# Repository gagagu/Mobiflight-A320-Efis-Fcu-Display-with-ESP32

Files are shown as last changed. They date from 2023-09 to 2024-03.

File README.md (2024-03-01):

# Mobiflight-A320-Efis-Fcu-Display-with-ESP32
A320 Efis/Fcu Display for Mobiflight with Esp32

## please read!
Eral has taken my project and created a new project as custom device for Mobiflight, so there is no need for using an ESP32 anymore.
See [here](https://github.com/elral/MF_FCU_EFIS_OLEDs)

## This project ist still in development!

The goal of this project is to create an A320 Efis and Fcu controlled by Mobiflight. I want to use it with Fexis A320 for MSFS 2020 but for make it easier on development i have used the A320 from FlyByWire first.

## old The Idea
Mobiflight (today) is not able to control Oled Displays so it's not possible to create Displays like neede for FCU or EFIS with different graphic content. But Mobiflight is able to use Text LCD Display. May idea was/is to use an Arduino to emulate an LCD Display but instead of sending text from Mobiflight to the display i will send commands. The Arduino receives the commands and sets the content of the Oled Display corresponding to the command.

For Example:
In Flightsim we pull the baro knob. Mobiflight detect this and send an command "setSTD" to the LCD Display by I2c bus. The Arduino receives the command and print "STD" to the Oled Display.

### In the project directories are always two subdirectories, "EfisOnly" and "EfisAndFcu". The first one is used the "old" idea. The second one is used the "new" idea (see below).

## the new Idea
With the new (in beta yet) Mobiflight feature for generic I2C Devices the emulation of the LCD Display is not needed anyore. There is now a direct i2c communication between the ESP32 and the Arduino Mega 2560 (Mobliblight).
This makes the code and Mobiflight handling easier.

## The Reality
In reality a Ardunio cannot be i2c bus master and slave, so it wasn't possible to communicate with Mobiflight and the Oled Display on one bus. I have made some tests to use the hardware i2c bus for Mobiflight communication and a Software emulated i2c bus for the Oled Display. It work.... (see: https://github.com/gagagu/Mobiflight-A320-Efis-Display-with-Arduino)
But not really good. It's too slow.

Thats the reason why I switched to an ESP32 board, which has two hardware i2c interfaces.
I've made my first tests only with one Oled Display for the left Efis and everything works fine.

Now, I am working on an extension to realize left and right Efis and the Fcu with one Esp32, for the Displays. Because the displays used all the same i2c address i have to add an i2c multiplexer to controll all displays.
You will need nearly three Arduino Mega 2560 for all Efis and Fcu Buttons and LED's to control. Yes, you can use Portexpander to use one Arduino Mega, but why. The expander is not much cheaper than an additionally used Arduino Mega....

## Current State
The code is nearly finished and the displays are working. For easier testing i have used the Fly By Wire A320 with Mobiflight and i am using the Mobiflight 10

## Installation
- Upload the EfisAndFcu.ino to yout ESP32 with Arduino Studio
- download the latest Mobiflight from GitHub (https://github.com/MobiFlight/MobiFlight-Connector/releases)
- download the lastest mobiflight_genericI2C_mega_<version>.hex from Mobiflight Firmware Source (https://github.com/MobiFlight/MobiFlight-FirmwareSource/releases) and copy it to the Mobniflight/Firmware directory
- download the mobiflight.gagagu_efis_fcu.device.json from my Repository (https://github.com/gagagu/Mobiflight-A320-Efis-Fcu-Display-with-ESP32/tree/main/Mobiflight/EfisAndFcu/Devices) and copy it to the Mobiflight/Devices directory.
- copy the mobiflight_genericI2C_mega.board.json from Mobiflight/Community/MobiFlight/boards to the Mobiflight/Boards directory.
- Start Mobiflight
- Upload the Mobiflight GenerisI2C Mega Firmware für the FCU Arduino
- Upload the FCU.mfmc (https://github.com/gagagu/Mobiflight-A320-Efis-Fcu-Display-with-ESP32/tree/main/Mobiflight/EfisAndFcu) Config to the FCU Arduino
- I am using a second Arduino Mega for the EFIS Knops and buttons (not display) and upload the "normal" Mobiflight firmware to ut and upload the EFIS_LEFT.mfmc to it.
- Open the  FBW_A320_EfisAndFcu.mcc (https://github.com/gagagu/Mobiflight-A320-Efis-Fcu-Display-with-ESP32/tree/main/Mobiflight/EfisAndFcu) in Mobiflight and push "run" (MSFS 2020 with FlyByWire A320 shoudl be running).

## Where are the stl's
I will create a folder with all stl files, soon. Or i will release them on Thingiverse and post the link here.

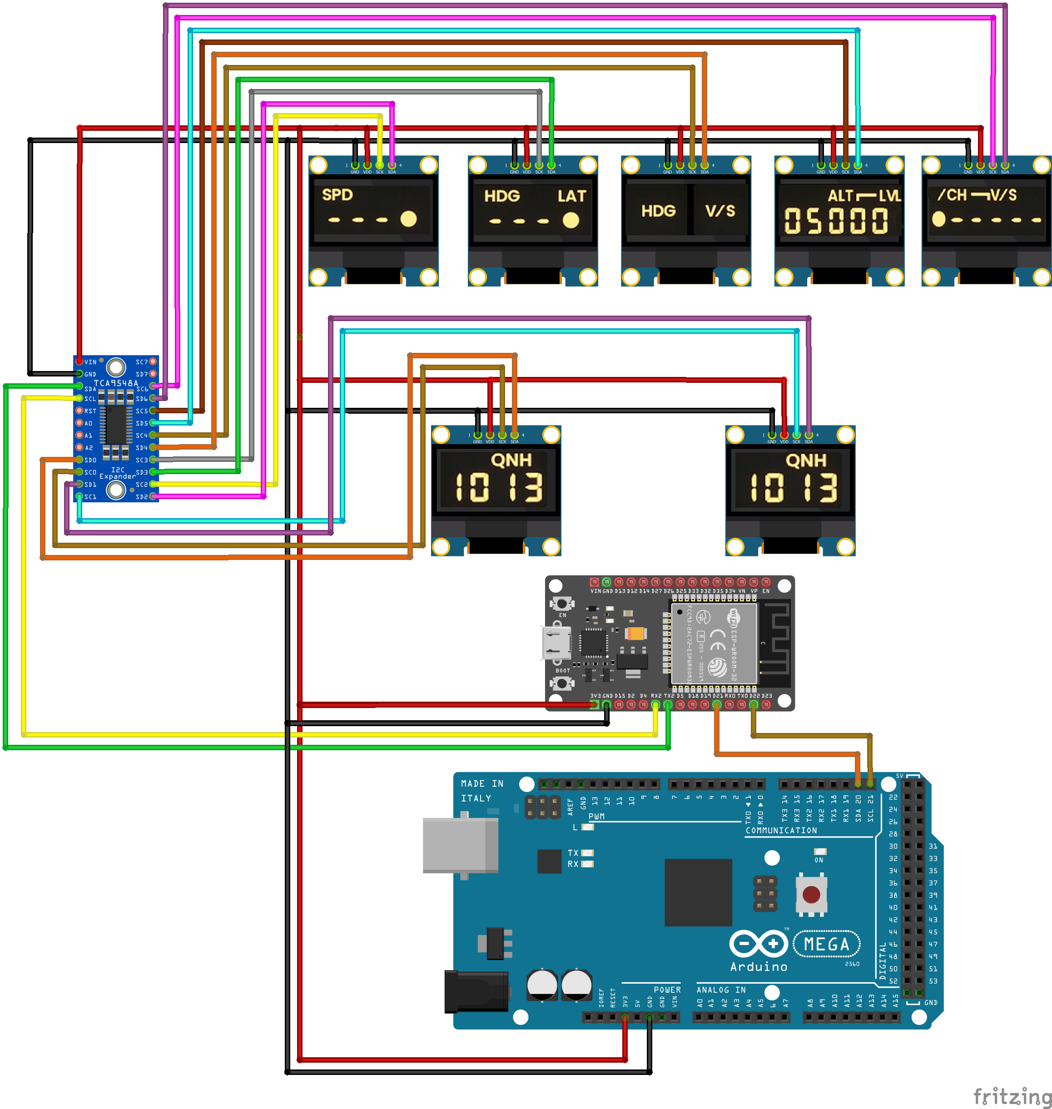
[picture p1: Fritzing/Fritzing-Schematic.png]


## Used designs
https://www.printables.com/de/model/494654-airbus-a320-efis-baro-knob

https://cults3d.com/en/3d-model/game/rotary-switch-5-x-45

https://www.thingiverse.com/thing:5253832

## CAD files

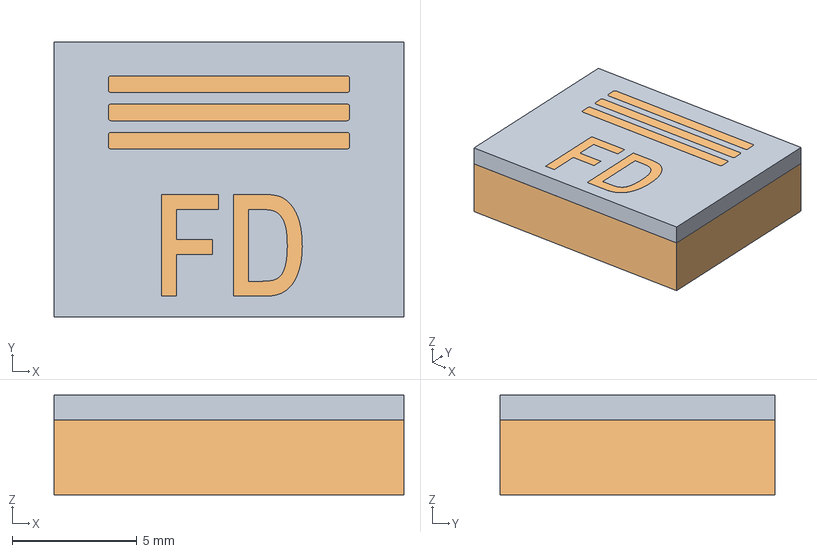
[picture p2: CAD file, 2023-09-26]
FreeCad/Korry/MulticolorPrinter/Korry_Multicolor.FCStd
14.0 x 11.0 x 4.00 mm
Schrift
Kappe

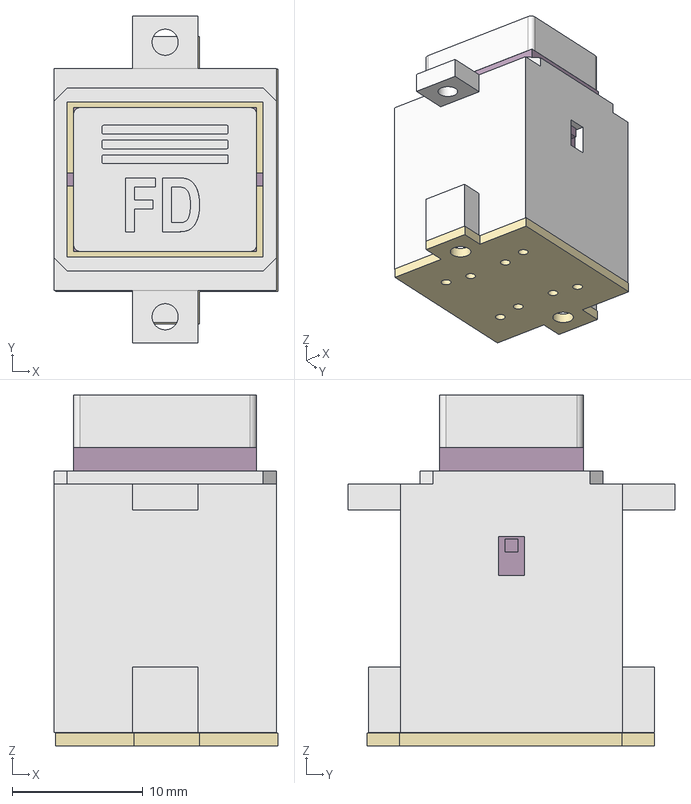
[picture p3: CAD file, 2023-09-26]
FreeCad/Korry/NonMulticolorPrinter/KorryNonMulticolor.FCStd
17.1 x 25.0 x 26.9 mm
inner
Platte

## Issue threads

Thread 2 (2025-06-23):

Frimware dont work

Albatrosnw19, 2025-06-23:
I have connected mega2560 and ESP32 but they are dont work.
1. I cant upload 'mobiflight_genericI2C_mega_2_5_1" to the 2560. it give me foult "There was an error on uploading the frimware to the board"
              23.06.2025 10:35:16(161): ExternAskToCheckLastVersion START from args -> Check BETA False
              23.06.2025 10:35:16(162): GetTheLastVersionNumberAvailable -> 10.5.3.0
              23.06.2025 10:35:16(163): GetInstalledVersion : detected -> 10.5.3.7
Also error if I try 10.5.3.0 version of mobiflight.
After I install version 2_5_0 of frimware I have next problems:
2. Only two displays are working after start boards (EFIS R and L). Another 5 (FCU) only after hot reconnect with TCA9548A.
3. On mobiflight I can see change digits (QNH) 1013,12,14... It is working, but on display only 1013!

gagagu, 2025-06-23:
Hi, have you ssen this?

_Eral has taken my project and created a new project as custom device for Mobiflight, so there is no need for using an ESP32 anymore. See [here](https://github.com/elral/MF_FCU_EFIS_OLEDs)_

Albatrosnw19, 2025-06-23:
There are too little description. Ok, thanks! I will write to him.

gagagu, 2025-06-24:
The Mobiflight Discord Server is a good way to contact him or me if you have further questions.

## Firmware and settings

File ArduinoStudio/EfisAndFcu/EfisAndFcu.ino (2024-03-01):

/*
This is only a Test and has to be set in an usable state
*/

//***************************************************************************************************
// comment this line if you are using (normally 1,3 inch) SH1106G displays for EFIS like following:
// #define EFIS_SSD1306_DISPLAYS 1
// 
// leave this line as it is if you are using (normally 0,9 inch) SSD1306 Displays for EFIS
#define EFIS_SSD1306_DISPLAYS 1
//***************************************************************************************************

#include <Wire.h>
#include <Adafruit_GFX.h>
#include <Adafruit_SSD1306.h>
#include <Adafruit_SH110X.h>
#include <Fonts/FreeSans18pt7b.h>
#include <Fonts/FreeSans9pt7b.h>
#include "Fonts/FreeSans8pt7b.h"
#include "Fonts/FreeSans7pt7b.h"
#include "Fonts/FreeSans6pt7b.h"
#include "Fonts/DSEG7Classic_Regular14pt7b.h"
#include "Fonts/DSEG7Classic_Regular15pt7b.h"
#include "Fonts/DSEG7Classic_Regular16pt7b.h"
#include "Fonts/DSEG7Classic_Regular18pt7b.h"
#include "Fonts/DSEG7Classic_Regular20pt7b.h"  //https://github.com/keshikan/DSEG and https://rop.nl/truetype2gfx/
#include "Fonts/DSEG7Classic_Regular22pt7b.h"

// Address and communication for Mobiflight
#define I2C_MOBIFLIGHT_ADDR 0x27
#define I2C_MOBIFLIGHT_SDA 21
#define I2C_MOBIFLIGHT_SCL 22

// I2c ports for communication with displays
#define I2C_DISPLAY_SDA 17
#define I2C_DISPLAY_SCL 16

#define SCREEN_WIDTH 128    // OLED display width, in pixels
#define SCREEN_HEIGHT 64    // OLED display height, in pixels
#define OLED_RESET     -1   // Reset pin # (or -1 if sharing Arduino reset pin)
#define SCREEN_ADDRESS 0x3c // address of the displays. All displays uses the same address

// address of the multiplexer to change the channels
#define TCA9548A_I2C_ADDRESS  0x70
#define TCA9548A_CHANNEL_EFIS_LEFT  0
#define TCA9548A_CHANNEL_EFIS_RIGHT 1
#define TCA9548A_CHANNEL_FCU_SPD    2
#define TCA9548A_CHANNEL_FCU_HDG    3
#define TCA9548A_CHANNEL_FCU_FPA    4
#define TCA9548A_CHANNEL_FCU_ALT    5
#define TCA9548A_CHANNEL_FCU_VS     6
#define TCA9548A_CHANNEL_UNUSED     7

#define MAX_LENGTH_MESSAGE          96 

enum {
    NOT_SYNCHRONIZED = 0,
    RECEIVE_COMMAND,
    RECEIVE_DATA
};
#define END_OF_I2C_MESSAGE              0x00
#define END_OF_I2C_COMMAND              0x0D      // carriage return in ASCII
#define END_OF_I2C_PARTIAL_MESSAGE      0x0A      // line feed in ASCII
int16_t _messageID = 0;
char _message[MAX_LENGTH_MESSAGE];
//bool _message_received = false;

TwoWire I2Ctwo = TwoWire(1);  // init second i2c bus

// Efis displays
#ifdef EFIS_SSD1306_DISPLAYS
  Adafruit_SSD1306 dEfis(SCREEN_WIDTH, SCREEN_HEIGHT, &I2Ctwo, OLED_RESET);
#else
  Adafruit_SH1106G dEfis = Adafruit_SH1106G(SCREEN_WIDTH, SCREEN_HEIGHT, &I2Ctwo, OLED_RESET);
#endif

// fcu displays
Adafruit_SH1106G dFcu = Adafruit_SH1106G(SCREEN_WIDTH, SCREEN_HEIGHT, &I2Ctwo, OLED_RESET);


// Efis left
char efisLeftBaroMode = 0x00;
char efisLeftBaroSelect = 0x00;
String efisLeftBaroValueHpa = "1013";
String efisLeftBaroValueHg = "2992";

// Efis right
char efisRightBaroMode = 0x00;
char efisRightBaroSelect = 0x00;
String efisRightBaroValueHpa = "1013";
String efisRightBaroValueHg = "2992";

// FCU Speed
char fcuSpeedManagedMode = 0x00;
String fcuSpeedValue = "0.26";

// FCU Hdg
char fcuHdgManagedMode = 0x00;
String fcuHdgValue = "000";

// FCU Trk Mode
char fcuTrkMode = 0x00;

// FCU Alt
char fcuAltManagedMode = 0x00;
String fcuAltValue = "00000";

// FCU VS
char fcuVsManagedMode = 0x00;
String fcuVsValue = "00000";
String fcuVsValueFpa = "-0.0";

void setup() {
  Serial.begin(115200);
  Serial.setDebugOutput(false);

  // setup i2c receive callback
  Wire.onReceive(onReceive);

  // init i2c busses
  Wire.begin((uint8_t)I2C_MOBIFLIGHT_ADDR,I2C_MOBIFLIGHT_SDA,I2C_MOBIFLIGHT_SCL,400000);
  I2Ctwo.begin(I2C_DISPLAY_SDA,I2C_DISPLAY_SCL,400000); // SDA pin , SCL pin , 400kHz frequency
  
  // //**************************
  // // Efis left
  // //**************************
  setTCAChannel(TCA9548A_CHANNEL_EFIS_LEFT);

#ifdef EFIS_SSD1306_DISPLAYS
  // SSD1306_SWITCHCAPVCC = generate display voltage from 3.3V internally
  if(!dEfis.begin(SSD1306_SWITCHCAPVCC, SCREEN_ADDRESS)) {
    Serial.println(F("SSD1306 allocation failed"));
    for(;;); // Don't proceed, loop forever
  }
#else
  dEfis.begin(SCREEN_ADDRESS, true); // Address 0x3C default
#endif

  dEfis.display();
  delay(50); // Pause
  updateDisplayEfisLeft();

  //**************************
  // Efis right
  //**************************
  setTCAChannel(TCA9548A_CHANNEL_EFIS_RIGHT);

#ifdef EFIS_SSD1306_DISPLAYS  
  if(!dEfis.begin(SSD1306_SWITCHCAPVCC, SCREEN_ADDRESS)) {
    Serial.println(F("SSD1306 allocation failed"));
    for(;;); // Don't proceed, loop forever
  }  
#else
  dEfis.begin(SCREEN_ADDRESS, true); // Address 0x3C default
#endif

  dEfis.display();
  delay(50); // Pause  
  updateDisplayEfisRight();


//**********************************************
// FCU SPD
//**********************************************
  setTCAChannel(TCA9548A_CHANNEL_FCU_SPD);
  dFcu.begin(SCREEN_ADDRESS, true); // Address 0x3C default
  dFcu.display();
  delay(50); // Pause
  updateDisplayFcuSpd();

//**********************************************
// FCU HDG
//**********************************************
  setTCAChannel(TCA9548A_CHANNEL_FCU_HDG);
  dFcu.begin(SCREEN_ADDRESS, true); // Address 0x3C default
  dFcu.display();
  delay(50); // Pause 
  updateDisplayFcuHdg();

//**********************************************
// FCU HDG and V/S or TRK and FPA.
//**********************************************
  setTCAChannel(TCA9548A_CHANNEL_FCU_FPA);
  dFcu.begin(SCREEN_ADDRESS, true); // Address 0x3C default
  dFcu.display();
  delay(50); // Pause 
  updateDisplayFcuFpa();

//**********************************************
// FCU ALT
//**********************************************
  setTCAChannel(TCA9548A_CHANNEL_FCU_ALT);
  dFcu.begin(SCREEN_ADDRESS, true); // Address 0x3C default
  dFcu.display();
  delay(50); // Pause 
  updateDisplayFcuAlt();

//**********************************************
// FCU Vs
//**********************************************
  setTCAChannel(TCA9548A_CHANNEL_FCU_VS);
  dFcu.begin(SCREEN_ADDRESS, true); // Address 0x3C default
  dFcu.display();
  delay(50); // Pause
  updateDisplayFcuVs();      
}

void loop() {
  updateDisplayEfisLeft();
  updateDisplayEfisRight();
  updateDisplayFcuSpd();  
  updateDisplayFcuHdg();  
  updateDisplayFcuAlt();  
  updateDisplayFcuFpa();
  updateDisplayFcuVs();  
}

/*
  switch multiplexer channel
*/
void setTCAChannel(byte i){
  I2Ctwo.beginTransmission(TCA9548A_I2C_ADDRESS);
  I2Ctwo.write(1 << i);
  I2Ctwo.endTransmission();  
  delay(5); // Pause
}

/*
  receive data from Mobiflight
*/
// callback function for I2C receive
void onReceive(int received_bytes) {

  static uint8_t byte_counter = 0;
  static uint8_t state = RECEIVE_COMMAND;
  char buffer[7] = {0};                                    // range is -32768 ... 32767 -> max. 6 character plus terminating NULL

  for (uint8_t i = 0; i < received_bytes; i++) {
    switch (state) {
      case NOT_SYNCHRONIZED:
        if (Wire.read() == END_OF_I2C_MESSAGE) {              // wait for end of message to get synchronized
          state = RECEIVE_COMMAND;
          byte_counter = 0;
        }
        break;

      case RECEIVE_COMMAND:
        buffer[i] = Wire.read();
        if (buffer[i] == END_OF_I2C_COMMAND) {
          buffer[i] = 0x00;                                   // terminate string
          _messageID = atoi(buffer);
          state = RECEIVE_DATA;                               // next bytes are Data Bytes
        }
        if (i >= 6) {                                         // buffer overflow for messageID
          state = NOT_SYNCHRONIZED;                          // something went wrong, get a new synchronization
          byte_counter = 0;
          return;
        }
        break;

      case RECEIVE_DATA:
        _message[byte_counter] = Wire.read();
        if (_message[byte_counter] == END_OF_I2C_MESSAGE) {    // end of message detected, prepare for receiving next messageID
          byte_counter = 0;
          state = RECEIVE_COMMAND;
          handleCommand();
          return;
        } else if(_message[byte_counter] == END_OF_I2C_PARTIAL_MESSAGE) {   // end of partial message detected, next transmission will be rest of message  
          return;                                             // keep receiving data
        } else {
          byte_counter++;                                     // get the next byte
        }
        break;

      default:
        break;
    }
  }
  state = NOT_SYNCHRONIZED;                                 // We shouldn't come here, something went wrong
}

void handleCommand(){
  switch(_messageID){
    case 0: // send in ASCII
      //Efis Left Baro Select
      //inHg=0, hPa=1
      efisLeftBaroSelect=_message[0];
      break;
    case 1:
      //Efis Left Baro Value Hpa
      efisLeftBaroValueHpa=_message;
      break;
    case 2:
      //Efis Left Baro Value Hg
      efisLeftBaroValueHg=_message;  
      break;
    case 3:
      //Efis Left Baro Mode
      //0 = QFE; 1 = QNH; 2 = STD, 3= Std
      efisLeftBaroMode=_message[0];  
      break;
    case 4: // send in ASCII
      //Efis Right Baro Select
      //inHg=0, hPa=1
      efisRightBaroSelect=_message[0];   
      break;
    case 5:
      //Efis Right Baro Value Hpa
      efisRightBaroValueHpa=_message;        
      break;
    case 6:
      //Efis Right Baro Value Hg
      efisRightBaroValueHg=_message;      
      break;
    case 7:
      //Efis Right Baro Mode
      //0 = QFE; 1 = QNH; 2 = STD; 3= STD
      efisRightBaroMode=_message[0];          
      break;      
    case 8:
      //Fcu Speed Value
      fcuSpeedValue=_message;         
      break;
    case 9:
      //Fcu Speed Managed
      //0 = No; 1 = Yes
      fcuSpeedManagedMode=_message[0];           
      break;
    case 10:
      //Fcu Hdg Value
      fcuHdgValue=_message;      
      break;
    case 11:
      //Fcu Hdg Managed
      //0 = No; 1 = Yes
      fcuHdgManagedMode=_message[0];          
      break;
    case 12:
      //Fcu Trk Mode
      //0 = No; 1 = Yes
      fcuTrkMode=_message[0];  
      break;
    case 13:
      //Fcu Alt Value
      fcuAltValue=_message;    
      break;
    case 14:
      //Fcu Alt Managed
      fcuAltManagedMode=_message[0];       
      break;
    case 15:
      //Fcu VS Value VS
      fcuVsValue=_message; 
      break;    
    case 16:
      //Fcu VS Value FPA
      fcuVsValueFpa=_message;    
      break;
    case 17:
      //Fcu VS Managed
      fcuVsManagedMode=_message[0]; 
      break;
  }

} //handleCommand


/*******************************************
Has to be redone, only tests
******************************************/
void updateDisplayEfisLeft(void)
{
  setTCAChannel(TCA9548A_CHANNEL_EFIS_LEFT);
 // Clear the buffer
  dEfis.clearDisplay();
  dEfis.setTextColor(SSD1306_WHITE);        // Draw white text
    //  Serial.print("efisLeftBaroMode:");
    //  Serial.println(efisLeftBaroMode);
  if(efisLeftBaroMode=='2' ||efisLeftBaroMode=='3'){
       dEfis.setFont(&DSEG7Classic_Regular22pt7b);
       dEfis.setCursor(10,60);             
       dEfis.println("5td");
  }else{
    if(efisLeftBaroMode=='0'){
      dEfis.setFont(&FreeSans9pt7b);
      dEfis.setTextSize(1);             
      dEfis.setCursor(0,15);             
      dEfis.println("QFE");  
    }else{
      dEfis.setFont(&FreeSans9pt7b);
      dEfis.setTextSize(1);             
      dEfis.setCursor(85,15);             
      dEfis.println("QNH");
    }
    if(efisLeftBaroSelect=='0'){  // send in ASCII
      dEfis.setFont(&DSEG7Classic_Regular20pt7b);
      dEfis.setCursor(0,60);             
      dEfis.println(efisLeftBaroValueHg); 
      dEfis.fillCircle(64, 60, 2, SSD1306_WHITE);
    }else {
      dEfis.setFont(&DSEG7Classic_Regular20pt7b);
      dEfis.setCursor(0,60);   
      dEfis.println(efisLeftBaroValueHpa);
    }
  }

  dEfis.display();
} //updateDisplayEfisLeft

void updateDisplayEfisRight(void)
{
  setTCAChannel(TCA9548A_CHANNEL_EFIS_RIGHT);
 // Clear the buffer
  dEfis.clearDisplay();
  dEfis.setTextColor(SSD1306_WHITE);        // Draw white text

  if(efisRightBaroMode=='2' || efisRightBaroMode=='3'){
       dEfis.setFont(&DSEG7Classic_Regular22pt7b);
       dEfis.setCursor(10,60);             
       dEfis.println("5td");
  }else{
    if(efisRightBaroMode=='0'){
      dEfis.setFont(&FreeSans9pt7b);
      dEfis.setTextSize(1);             
      dEfis.setCursor(0,15);             
      dEfis.println("QFE");  
    }else{
      dEfis.setFont(&FreeSans9pt7b);
      dEfis.setTextSize(1);             
      dEfis.setCursor(85,15);             
      dEfis.println("QNH");
    }
    if(efisRightBaroSelect=='0'){  // send in ASCII
      dEfis.setFont(&DSEG7Classic_Regular20pt7b);
      dEfis.setCursor(0,60);             
      dEfis.println(efisRightBaroValueHg); 
      dEfis.fillCircle(64, 60, 2, SSD1306_WHITE);
    }else {
      dEfis.setFont(&DSEG7Classic_Regular20pt7b);
      dEfis.setCursor(0,60);   
      dEfis.println(efisRightBaroValueHpa);
    }
  }

  dEfis.display();
} //updateDisplayEfisRight



void updateDisplayFcuSpd(void)
{

  setTCAChannel(TCA9548A_CHANNEL_FCU_SPD);

  // Clear the buffer
  dFcu.clearDisplay();
  dFcu.setTextColor(SSD1306_WHITE);        // Draw white text

  dFcu.setFont(&FreeSans8pt7b);
  dFcu.setTextSize(1); 

  if(fcuSpeedValue[0]=='0')
  {
    dFcu.setCursor(65,20);       
    dFcu.println("MACH");
    if(fcuSpeedValue[3]==0x00)
    {
      fcuSpeedValue[3]='0';
    }
  }else{
    dFcu.setCursor(25,20);             
    dFcu.println("SPD");
  }

  if(fcuSpeedManagedMode=='1')
  {
    dFcu.setFont(&DSEG7Classic_Regular15pt7b);
    dFcu.setCursor(28,55);             
    dFcu.println("---"); 
    dFcu.fillCircle(104, 40, 3, SSD1306_WHITE);
  }
  else{
    dFcu.setFont(&DSEG7Classic_Regular15pt7b);
    dFcu.setCursor(28,55);             
    dFcu.println(fcuSpeedValue); 
  }

  dFcu.display();
}


void updateDisplayFcuHdg(void)
{
  String strHdgValue="000";
  
  // FCU Hdg
  setTCAChannel(TCA9548A_CHANNEL_FCU_HDG);

  // Clear the buffer
  dFcu.clearDisplay();
  dFcu.setTextColor(SSD1306_WHITE);        // Draw white text

  dFcu.setFont(&FreeSans8pt7b);
  dFcu.setTextSize(1); 


  if(fcuTrkMode=='0')
  {
    dFcu.setCursor(20,20);             
    dFcu.println("HDG");
  }else{
    dFcu.setCursor(60,20);       
    dFcu.println("TRK");
  }

  dFcu.setCursor(95,20);       
  dFcu.println("LAT");

  if(fcuHdgManagedMode=='1')
  {
    dFcu.setFont(&DSEG7Classic_Regular15pt7b);
    dFcu.setCursor(28,55);             
    dFcu.println("---"); 
    dFcu.fillCircle(104, 40, 3, SSD1306_WHITE);
  }
  else{
    dFcu.setFont(&DSEG7Classic_Regular15pt7b);
    dFcu.setCursor(28,55);   
 
    if(fcuHdgValue[1]==0x00)
    {
      strHdgValue[0]='0';
      strHdgValue[1]='0';
      strHdgValue[2]=fcuHdgValue[0];
    }else{
      if(fcuHdgValue[2]==0x00)
      {
        strHdgValue[0]='0';
        strHdgValue[1]=fcuHdgValue[0];
        strHdgValue[2]=fcuHdgValue[1];
      }else{
        strHdgValue[0]=fcuHdgValue[0];
        strHdgValue[1]=fcuHdgValue[1];
        strHdgValue[2]=fcuHdgValue[2];
      }      
    }
    dFcu.println(strHdgValue); 
  }

  dFcu.display();
}

void updateDisplayFcuFpa(void)
{
  setTCAChannel(TCA9548A_CHANNEL_FCU_FPA);

  // Clear the buffer
  dFcu.clearDisplay();
  dFcu.setTextColor(SSD1306_WHITE);        // Draw white text

  dFcu.setFont(&FreeSans8pt7b);
  dFcu.setTextSize(1); 

  if(fcuTrkMode=='0')
  {
    dFcu.setCursor(30,30);             
    dFcu.println("HDG");

    dFcu.setCursor(74,30);       
    dFcu.println("V/S");
  }else{
    dFcu.setCursor(30,45);             
    dFcu.println("TRK");

    dFcu.setCursor(74,45);       
    dFcu.println("FPA");
  }
  dFcu.display();
}

void updateDisplayFcuAlt(void)
{
  String strAltValue="00000";

  setTCAChannel(TCA9548A_CHANNEL_FCU_ALT);
  // Clear the buffer
  dFcu.clearDisplay();
  dFcu.setTextColor(SSD1306_WHITE);        // Draw white text
  
  dFcu.setFont(&FreeSans8pt7b);
  dFcu.setTextSize(1); 

  dFcu.setCursor(52,20);             
  dFcu.print("ALT");

  dFcu.setCursor(94,20);   
  dFcu.print("LVL");
  dFcu.print("/");

  dFcu.drawFastVLine(82, 15, 5, SSD1306_WHITE);
  dFcu.drawFastHLine(82, 15, 10, SSD1306_WHITE);

  if(fcuAltValue[3]==0x00)
  {
    strAltValue[0]='0';
    strAltValue[1]='0';
    strAltValue[2]=fcuAltValue[0];
    strAltValue[3]=fcuAltValue[1];
    strAltValue[4]=fcuAltValue[2];
  }else{
    if(fcuAltValue[4]==0x00)
    {
      strAltValue[0]='0';
      strAltValue[1]=fcuAltValue[0];
      strAltValue[2]=fcuAltValue[1];
      strAltValue[3]=fcuAltValue[2];
      strAltValue[4]=fcuAltValue[3];        
    }else{
      strAltValue[0]=fcuAltValue[0];
      strAltValue[1]=fcuAltValue[1];
      strAltValue[2]=fcuAltValue[2];
      strAltValue[3]=fcuAltValue[3];
      strAltValue[4]=fcuAltValue[4];        
    }      
  }

  dFcu.setFont(&DSEG7Classic_Regular15pt7b);
  dFcu.setCursor(0,55);             
  dFcu.print(strAltValue); 
  
  if(fcuAltManagedMode=='1')
  {
    dFcu.fillCircle(124, 39, 3, SSD1306_WHITE);
  }

   dFcu.display();
} //updateDisplayFcuAlt


void updateDisplayFcuVs(void)
{
  String strVrValue="0000";

  setTCAChannel(TCA9548A_CHANNEL_FCU_VS);

  // Clear the buffer
  dFcu.clearDisplay();
  dFcu.setTextColor(SSD1306_WHITE);        // Draw white text
  
  dFcu.setFont(&FreeSans8pt7b);
  dFcu.setTextSize(1); 

  dFcu.setCursor(2,20);             
  dFcu.print("CH");

  if(fcuTrkMode=='0')
  {
    dFcu.setCursor(40,20);   
    dFcu.print("V/S");
  }else{
    dFcu.setCursor(86,20);   
    dFcu.print("FPA");
  }



  dFcu.drawFastHLine(26, 15, 10, SSD1306_WHITE);
  dFcu.drawFastVLine(36, 15, 5, SSD1306_WHITE);

  if(fcuVsManagedMode=='1')
  {
    dFcu.setFont(&DSEG7Classic_Regular15pt7b);
    dFcu.setCursor(0,55);   
    dFcu.print("-----"); 
  }else{
    if(fcuTrkMode=='0')
    {
      if(fcuVsValue[1]==0x00){
          dFcu.setFont(&FreeSans18pt7b);
          dFcu.setCursor(0,50);   
          dFcu.print("+"); 
          
          strVrValue[0]='0';
          strVrValue[1]='0';
          strVrValue[2]='0';
          strVrValue[3]='0';

          dFcu.setFont(&DSEG7Classic_Regular15pt7b);
          dFcu.setCursor(24,55);   
          dFcu.print(strVrValue); 
      }else{
        if(fcuVsValue[0]=='-')
        {
          dFcu.setFont(&DSEG7Classic_Regular15pt7b);
          dFcu.setCursor(0,55);   
          dFcu.print("-"); 

          if(fcuVsValue[4]==0x00){
            strVrValue[0]='0';
            strVrValue[1]=fcuVsValue[1];
            strVrValue[2]=fcuVsValue[2];
            strVrValue[3]=fcuVsValue[3];         
          }else{
            strVrValue[0]=fcuVsValue[1];
            strVrValue[1]=fcuVsValue[2];
            strVrValue[2]=fcuVsValue[3];
            strVrValue[3]=fcuVsValue[4];      
          }
          dFcu.print(strVrValue); 
        }else{
          dFcu.setFont(&FreeSans18pt7b);
          dFcu.setCursor(0,50);   
          dFcu.print("+"); 
          
          if(fcuVsValue[3]==0x00){
            strVrValue[0]='0';
            strVrValue[1]=fcuVsValue[0];
            strVrValue[2]=fcuVsValue[1];
            strVrValue[3]=fcuVsValue[2];         
          }else{
            strVrValue[0]=fcuVsValue[0];
            strVrValue[1]=fcuVsValue[1];
            strVrValue[2]=fcuVsValue[2];
            strVrValue[3]=fcuVsValue[3];      
          }

          dFcu.setFont(&DSEG7Classic_Regular15pt7b);
          dFcu.setCursor(24,55);   
          dFcu.print(strVrValue); 
        }
      }
    }else{
     
      if(fcuVsValueFpa[0]=='-')
       {
        dFcu.setFont(&DSEG7Classic_Regular15pt7b);
        dFcu.setCursor(0,55);  

        if(fcuVsValueFpa[2]==0x00)
        {
          strVrValue=fcuVsValueFpa + ".0";
        }else{
          strVrValue=fcuVsValueFpa;
        }       
        dFcu.print(strVrValue);   
      } else{
        dFcu.setFont(&FreeSans18pt7b);
        dFcu.setCursor(0,50);   
        dFcu.print("+");    

        if(fcuVsValueFpa=="0")
        {
          strVrValue="0.0";
        }else{
          if(fcuVsValueFpa[1]==0x00)
          {
            strVrValue=fcuVsValueFpa + ".0";
          } else{
            strVrValue[0]=fcuVsValueFpa[0];
            strVrValue[1]=fcuVsValueFpa[1];
            strVrValue[2]=fcuVsValueFpa[2];
            strVrValue[3]=0x00;
          }
        }

        dFcu.setFont(&DSEG7Classic_Regular15pt7b);
        dFcu.setCursor(24,55);  
        dFcu.print(strVrValue);             
      }
   
    }
  }
  dFcu.display();
}

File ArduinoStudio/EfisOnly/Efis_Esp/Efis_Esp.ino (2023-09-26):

#include <Wire.h>
#include <Adafruit_GFX.h>
#include <Adafruit_SSD1306.h>
#include <Fonts/FreeSans9pt7b.h>
#include "Fonts/DSEG7Classic_Regular20pt7b.h"  //https://github.com/keshikan/DSEG and https://rop.nl/truetype2gfx/
#include "Fonts/DSEG7Classic_Regular22pt7b.h"

#define I2C_MOBIFLIGHT_ADDR 0x27
#define I2C_MOBIFLIGHT_SDA 21
#define I2C_MOBIFLIGHT_SCL 22

#define I2C_DISPLAY_SDA 17
#define I2C_DISPLAY_SCL 16

TwoWire I2Ctwo = TwoWire(1);

#define SCREEN_WIDTH 128 // OLED display width, in pixels
#define SCREEN_HEIGHT 64 // OLED display height, in pixels
#define OLED_RESET     -1 // Reset pin # (or -1 if sharing Arduino reset pin)
#define SCREEN_ADDRESS 0x3C ///< See datasheet for Address; 0x3D for 128x64, 0x3C for 128x32
Adafruit_SSD1306 display(SCREEN_WIDTH, SCREEN_HEIGHT, &I2Ctwo, OLED_RESET);

bool isStd = false;
bool isHpa = true;
String valHpa="8888";
String valHg="88,88";



void setup() {
  Serial.begin(115200);
  Serial.setDebugOutput(false);
  Wire.onReceive(onReceive);

  Wire.begin((uint8_t)I2C_MOBIFLIGHT_ADDR,I2C_MOBIFLIGHT_SDA,I2C_MOBIFLIGHT_SCL,400000);
  I2Ctwo.begin(I2C_DISPLAY_SDA,I2C_DISPLAY_SCL,400000); // SDA pin 16, SCL pin 17, 400kHz frequency

  // SSD1306_SWITCHCAPVCC = generate display voltage from 3.3V internally
  if(!display.begin(SSD1306_SWITCHCAPVCC, SCREEN_ADDRESS)) {
    Serial.println(F("SSD1306 allocation failed"));
    for(;;); // Don't proceed, loop forever
  }

  // Show initial display buffer contents on the screen --
  // the library initializes this with an Adafruit splash screen.
  display.display();
  delay(2000); // Pause for 2 seconds

  updateDisplay();

}

void loop() {
 // delay(5);
}


void onReceive(int len){
  char msgArray[9]="";

  // // if smaller than 32 ignore
   if(Wire.available()==32)
   {
     for (int i=0; i <= 8; i++){
       uint8_t hibits = (uint8_t)Wire.read();      
       Wire.read(); // ignore
       uint8_t lowbits = (uint8_t)Wire.read(); 
       Wire.read(); // ignore

       msgArray[i] = msgArray[i] | (hibits & 0xf0);
       msgArray[i] = msgArray[i] | ((lowbits & 0xf0)>>4);
       if(msgArray[i] == 0x20){
         msgArray[i]='\0';
       }
     }
     if(msgArray[7] != '\0'){
         msgArray[8]='\0';
     }

    //Serial.println(msgArray);
    handleCommand(String(msgArray));

   }else{
    while(Wire.available()){
      Wire.read();
    }
   }
}

void handleCommand(String command){
    
      Serial.println(command);

   if(command.startsWith("#0")){
    valHpa=command.substring(2);
    if(valHpa.substring(0,1)=="5"){
      valHpa="0"+ valHpa.substring(1);
    }
   }
   if(command.startsWith("#1")){
    valHg=command.substring(2);
   }
   if(command.startsWith("#2")){
     if(command.substring(2)=="0"){
      isHpa=false;
     }else{
       isHpa=true;
     }
   }
   if(command.startsWith("#3")){
     if(command.substring(2)=="1"){
      isStd=true;
     }else{
       isStd=false;
     }
   } 

   updateDisplay();
}

void updateDisplay(void)
{

 // Clear the buffer
  display.clearDisplay();
  display.setTextColor(SSD1306_WHITE);        // Draw white text

  if(isStd){
      display.setFont(&DSEG7Classic_Regular22pt7b);
      display.setCursor(20,60);             
      display.println("5td");
  }else{
    display.setFont(&FreeSans9pt7b);
    display.setTextSize(1);             
    display.setCursor(85,15);             
    display.println("QNH");
    if(isHpa){
        display.setFont(&DSEG7Classic_Regular20pt7b);
        if(valHpa.length()==3)
        {
          display.setCursor(32,60);             
        }else{
          display.setCursor(0,60);     
        }
        display.println(valHpa);
    }else {
        display.setFont(&DSEG7Classic_Regular20pt7b);
        display.setCursor(0,60);             
        display.println(valHg); 
    }
  }

  // Show the display buffer on the screen. You MUST call display() after
  // drawing commands to make them visible on screen!
  display.display();

}
